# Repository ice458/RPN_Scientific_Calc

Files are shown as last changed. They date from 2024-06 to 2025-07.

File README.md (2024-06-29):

# RPN Scientific Calculator
RPN Scientific Calculator with PIC32CM2532LE00048.  
Reverse Polish notation with 4-element stack.  
This calculator uses a proprietary decimal floating point library to perform calculations.  
This project was created using MPLAB X IDE v6.20, XC32 v4.35, and MCC v5.50.  
For more information, please visit [this site.](https://ice458.wordpress.com/rpn%e9%96%a2%e6%95%b0%e9%9b%bb%e5%8d%93/)

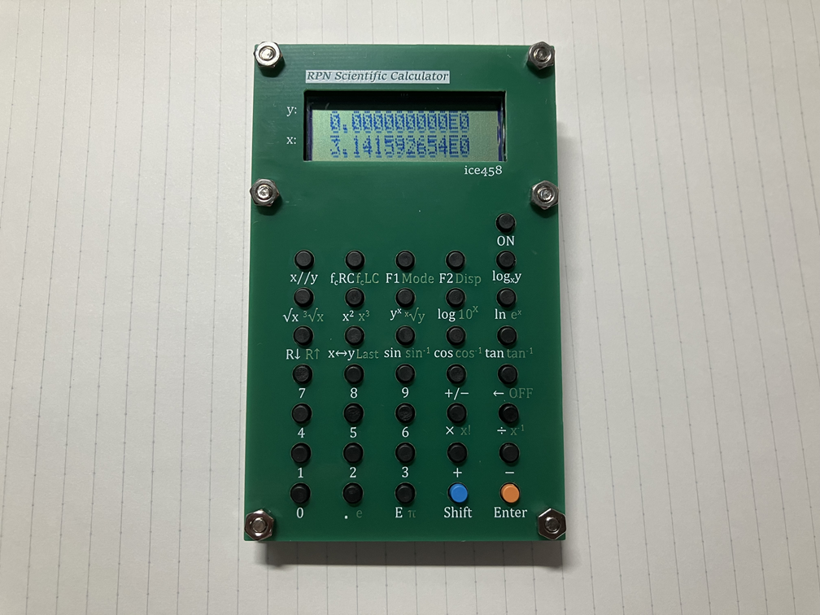
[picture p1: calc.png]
  

## License

This project is licensed under the MIT License. See the [LICENSE](LICENSE) file for details.

## Notice Regarding Third-Party Code

Please note that the copyright of the files contained in the directories [src/packs](src/packs) and [src/config](src/config) does not belong to ice458. These files include code that is subject to third-party licenses. Please refer to the comments at the top of these files for specific licensing information.

The directories [src/packs](src/packs) and [src/config](src/config) may contain files licensed under the Apache License 2.0 and Microchip's proprietary license. You must comply with these licenses when using or distributing these files.

### Apache License 2.0

Portions of this project are licensed under the Apache License 2.0. You may obtain a copy of the License at http://www.apache.org/licenses/LICENSE-2.0.

### Microchip Proprietary License

Certain files are subject to Microchip's proprietary license. These files are provided by Microchip "as is" without any warranties, and you may use Microchip software and any derivatives exclusively with Microchip products. Refer to the comments within the files for more details on the terms and conditions.

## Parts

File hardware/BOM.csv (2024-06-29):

Reference | Value | Datasheet | Footprint | Qty
BT1 | AAA | ~ | Battery:BatteryHolder_Keystone_2466_1xAAA | 1
C1,C7,C11,C14 | GRM188R71E105KA12 | ~ | Capacitor_SMD:C_0603_1608Metric | 4
C2,C3,C8,C9,C10,C12,C13 | GRM188F11H104ZA01 | ~ | Capacitor_SMD:C_0603_1608Metric | 7
C4 | GRM31CR61A107MEA8 | ~ | Capacitor_SMD:C_1206_3216Metric | 1
C5,C6 | GRM188R6YA106MA73 | ~ | Capacitor_SMD:C_0603_1608Metric | 2
D1,D2,D3,D4,D5,D6,D7,D8 | 1N4148W | ~ | Diode_SMD:D_SOD-123 | 8
J1 | PICKIT4/5 | ~ | Connector_PinHeader_2.54mm:PinHeader_1x08_P2.54mm_Vertical | 1
L1 | DFE252010P-4R7M=P2 | ~ | Inductor_SMD:L_1008_2520Metric | 1
L2 | DFE252012F-100M=P2 | ~ | Inductor_SMD:L_1008_2520Metric | 1
Q1 | 2N7002H | ~ | Package_TO_SOT_SMD:SOT-23 | 1
Q2 | AO3415A | ~ | Package_TO_SOT_SMD:SOT-23 | 1
R1,R2,R3,R6,R7,R8,R9,R10,R11 | ERJ-3EKF1002V | ~ | Resistor_SMD:R_0603_1608Metric | 9
R4 | ERJ-3EKF1003V | ~ | Resistor_SMD:R_0603_1608Metric | 1
R5 | ERJ-3EKF1001V | ~ | Resistor_SMD:R_0603_1608Metric | 1
SW1,SW2,SW3,SW4,SW5,SW6,SW7,SW8,SW9,SW10,SW11,SW12,SW13,SW14,SW15,SW16,SW17,SW18,SW19,SW20,SW21,SW22,SW23,SW24,SW25,SW26,SW27,SW28,SW29,SW30,SW31,SW32,SW33,SW34,SW35,SW36 | DTS-63-N-V-BLK | ~ | Button_Switch_THT:SW_PUSH_6mm | 36
U1 | AQM1602Y-RN-GBW | ~ | My_Display:AQM1602Y-RN-GBW | 1
U2 | XC9140A331MR-G | ~ | Package_TO_SOT_SMD:SOT-23-5 | 1
U3 | PIC32CM2532LE00048-I/Y8X | ~ | Package_QFP:TQFP-48_7x7mm_P0.5mm | 1

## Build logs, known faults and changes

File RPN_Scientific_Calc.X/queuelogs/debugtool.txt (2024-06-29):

268 1719630796392 GEN4_CONNECT_DIAGNOSTICS:MPLABCommTool is NOT null
268 1719630796393 GEN4_CONNECT_DIAGNOSTICS:AttachedToolPID = 9012, AttachedToolVID = 4d8
268 1719630796393 GEN4_CONNECT_DIAGNOSTICS:transport type = USB
268 1719630796394 GEN4_CONNECT_DIAGNOSTICS:AttachedToolPID = 9012, AttachedToolVID = 4d8
268 1719630796505 com.microchip.mplab.mdbcore.RealICETool.RIDbgToolCom
268 1719630796505 GEN4_CONNECT_DIAGNOSTICS:Before MPLABCommTool.Connect()
268 1719630796506 GEN4_CONNECT_DIAGNOSTICS:After MPLABCommTool.Connect()
268 1719630796551 GEN4_CONNECT_DIAGNOSTICS:Adding new plug and play observer com.microchip.mplab.mdbcore.RI4Tool.RI4ToolBase$RI4PlugNPlayObserver@505a1f4a
268 1719630796551 GEN4_CONNECT_DIAGNOSTICS:Begin PlugNPlayObservers list dump:
268 1719630796552 GEN4_CONNECT_DIAGNOSTICS:com.microchip.mplab.mdbcore.RI4Tool.RI4ToolBase$RI4PlugNPlayObserver@505a1f4a
268 1719630796552 GEN4_CONNECT_DIAGNOSTICS:End PlugNPlayObservers list dump:
268 1719630796557 GEN4_CONNECT_DIAGNOSTICS:Registering for alternate PNP notifications. CommPnPCriteria.cPIDList = [2177, 2179, 217a, 2141, 9017, 901b, 9036, 9035], CommPnPCriteria.cSerialNumber = bur191452614

268 1719630797563 GEN4_TO_CONTROLLER_LOG:GEN4_INIT_INT_LOG_PIC32CM2532LE00048 Pre:init
268 1719630797563 GEN4_TO_CONTROLLER_LOG:GEN4_INIT_INT_LOG_PIC32CM2532LE00048 Payload
268 1719630797564 GEN4_TO_CONTROLLER_LOG:GEN4_INIT_INT_LOG_PIC32CM2532LE00048 DeviceInfo: Values:
268 1719630797564 GEN4_TO_CONTROLLER_LOG:GEN4_INIT_INT_LOG_PIC32CM2532LE00048 DeviceInfo: pcAddress = 7fffffffffffffff, Vpp = 3.30, useRowEraseIfVoltageIsLow = false, voltageBelowWhichUseRowErase = 0.00, deviceName = PIC32CM2532LE00048, programmerType = NVMCTRL_U2207
268 1719630797564 GEN4_TO_CONTROLLER_LOG:GEN4_INIT_INT_LOG_PIC32CM2532LE00048 DeviceInfo: MemInfo values:
268 1719630797564 GEN4_TO_CONTROLLER_LOG:GEN4_INIT_INT_LOG_PIC32CM2532LE00048 DeviceInfo: mask = ffffffff, exists = true, startAddr = 00000000, endAddr = 20007fff, rowSize = 0100, rowEraseSize = 0100, addrInc = 0004, widthProgram = 0004
268 1719630797564 GEN4_TO_CONTROLLER_LOG:GEN4_INIT_INT_LOG_PIC32CM2532LE00048 DeviceInfo: mask = ffffffff, exists = true, startAddr = 00804000, endAddr = 0080c04f, rowSize = 0100, rowEraseSize = 0000, addrInc = 0004, widthProgram = 0004
268 1719630797564 GEN4_TO_CONTROLLER_LOG:GEN4_INIT_INT_LOG_PIC32CM2532LE00048 DeviceInfo: mask = 0000, exists = false, startAddr = 00000000, endAddr = 00000000, rowSize = 0000, rowEraseSize = 0000, addrInc = 0000, widthProgram = 0000
268 1719630797564 GEN4_TO_CONTROLLER_LOG:GEN4_INIT_INT_LOG_PIC32CM2532LE00048 DeviceInfo: mask = 0000, exists = false, startAddr = 00000000, endAddr = 00000000, rowSize = 0000, rowEraseSize = 0000, addrInc = 0000, widthProgram = 0000
268 1719630797564 GEN4_TO_CONTROLLER_LOG:GEN4_INIT_INT_LOG_PIC32CM2532LE00048 DeviceInfo: mask = ffffffff, exists = true, startAddr = 00804008, endAddr = 008040ff, rowSize = 0100, rowEraseSize = 0000, addrInc = 0004, widthProgram = 0004
268 1719630797565 GEN4_TO_CONTROLLER_LOG:GEN4_INIT_INT_LOG_PIC32CM2532LE00048 DeviceInfo: mask = 0000, exists = false, startAddr = 00000000, endAddr = 00000000, rowSize = 0000, rowEraseSize = 0100, addrInc = 0000, widthProgram = 0000
268 1719630797565 GEN4_TO_CONTROLLER_LOG:GEN4_INIT_INT_LOG_PIC32CM2532LE00048 DeviceInfo: mask = 0000, exists = false, startAddr = 00000000, endAddr = 00000000, rowSize = 0000, rowEraseSize = 0000, addrInc = 0004, widthProgram = 0004
268 1719630797565 GEN4_TO_CONTROLLER_LOG:GEN4_INIT_INT_LOG_PIC32CM2532LE00048 DeviceInfo: mask = ffffffff, exists = true, startAddr = 40000000, endAddr = e000efff, rowSize = 0000, rowEraseSize = 0000, addrInc = 0004, widthProgram = 0004
268 1719630797565 GEN4_TO_CONTROLLER_LOG:GEN4_INIT_INT_LOG_PIC32CM2532LE00048 DeviceInfo: mask = 0000, exists = true, startAddr = 00400000, endAddr = 00401ffe, rowSize = 0000, rowEraseSize = 0000, addrInc = 0004, widthProgram = 0004
268 1719630797565 GEN4_TO_CONTROLLER_LOG:GEN4_INIT_INT_LOG_PIC32CM2532LE00048 DeviceInfo: mask = 0000, exists = false, startAddr = 00000000, endAddr = 00000000, rowSize = 0000, rowEraseSize = 0000, addrInc = 0000, widthProgram = 0000
268 1719630797565 GEN4_TO_CONTROLLER_LOG:GEN4_INIT_INT_LOG_PIC32CM2532LE00048 DeviceInfo: mask = 0000, exists = false, startAddr = 00000000, endAddr = 00000000, rowSize = 0000, rowEraseSize = 0000, addrInc = 0004, widthProgram = 0004
268 1719630797565 GEN4_TO_CONTROLLER_LOG:GEN4_INIT_INT_LOG_PIC32CM2532LE00048 DeviceInfo: mask = 0000, exists = false, startAddr = 00000000, endAddr = 00000000, rowSize = 0000, rowEraseSize = 0000, addrInc = 0004, widthProgram = 0004
268 1719630797565 GEN4_TO_CONTROLLER_LOG:GEN4_INIT_INT_LOG_PIC32CM2532LE00048 DeviceInfo: mask = 0000, exists = false, startAddr = 00000000, endAddr = 00000000, rowSize = 0000, rowEraseSize = 0000, addrInc = 0000, widthProgram = 0000
268 1719630797565 GEN4_TO_CONTROLLER_LOG:GEN4_INIT_INT_LOG_PIC32CM2532LE00048 DeviceInfo: mask = 0000, exists = false, startAddr = 00000000, endAddr = 00000000, rowSize = 0000, rowEraseSize = 0000, addrInc = 0000, widthProgram = 0000
268 1719630797565 GEN4_TO_CONTROLLER_LOG:GEN4_INIT_INT_LOG_PIC32CM2532LE00048 DeviceInfo: mask = 0000, exists = false, startAddr = 00000000, endAddr = 00000000, rowSize = 0000, rowEraseSize = 0000, addrInc = 0000, widthProgram = 0000
268 1719630797565 GEN4_TO_CONTROLLER_LOG:GEN4_INIT_INT_LOG_PIC32CM2532LE00048 DeviceInfo: mask = 0000, exists = false, startAddr = 00000000, endAddr = 00000000, rowSize = 0000, rowEraseSize = 0000, addrInc = 0000, widthProgram = 0000
268 1719630797565 GEN4_TO_CONTROLLER_LOG:GEN4_INIT_INT_LOG_PIC32CM2532LE00048 DeviceInfo: mask = 7fffffff, exists = true, startAddr = 41002018, endAddr = 4100201b, rowSize = 0001, rowEraseSize = 0000, addrInc = 0001, widthProgram = 0001
268 1719630797565 GEN4_TO_CONTROLLER_LOG:GEN4_INIT_INT_LOG_PIC32CM2532LE00048 DeviceInfo: mask = 0000, exists = false, startAddr = 00000000, endAddr = 00000000, rowSize = 0000, rowEraseSize = 0000, addrInc = 0000, widthProgram = 0000
268 1719630797565 GEN4_TO_CONTROLLER_LOG:GEN4_INIT_INT_LOG_PIC32CM2532LE00048 DeviceInfo: mask = 0000, exists = false, startAddr = 00000000, endAddr = 00000000, rowSize = 0000, rowEraseSize = 0000, addrInc = 0000, widthProgram = 0000
268 1719630797565 GEN4_TO_CONTROLLER_LOG:GEN4_INIT_INT_LOG_PIC32CM2532LE00048 DeviceInfo: mask = 0000, exists = false, startAddr = 00000000, endAddr = 00000000, rowSize = 0000, rowEraseSize = 0000, addrInc = 0000, widthProgram = 0000
268 1719630797565 GEN4_TO_CONTROLLER_LOG:GEN4_INIT_INT_LOG_PIC32CM2532LE00048 DeviceInfo: mask = 0000, exists = false, startAddr = 00000000, endAddr = 00000000, rowSize = 0000, rowEraseSize = 0000, addrInc = 0000, widthProgram = 0000
268 1719630797565 GEN4_TO_CONTROLLER_LOG:GEN4_INIT_INT_LOG_PIC32CM2532LE00048 DeviceInfo: mask = 0000, exists = false, startAddr = 00000000, endAddr = 00000000, rowSize = 0000, rowEraseSize = 0000, addrInc = 0000, widthProgram = 0000
268 1719630797565 GEN4_TO_CONTROLLER_LOG:GEN4_INIT_INT_LOG_PIC32CM2532LE00048 DeviceInfo: mask = 0000, exists = false, startAddr = 00000000, endAddr = 00000000, rowSize = 0000, rowEraseSize = 0000, addrInc = 0000, widthProgram = 0000
268 1719630797565 GEN4_TO_CONTROLLER_LOG:GEN4_INIT_INT_LOG_PIC32CM2532LE00048 DeviceInfo: CfgRequiredBitsMask Values:
268 1719630797566 GEN4_TO_CONTROLLER_LOG:GEN4_INIT_INT_LOG_PIC32CM2532LE00048 Address = 00804000, Mask = fe00ffbf
268 1719630797566 GEN4_TO_CONTROLLER_LOG:GEN4_INIT_INT_LOG_PIC32CM2532LE00048 Address = 00804004, Mask = 000003ff
268 1719630797566 GEN4_TO_CONTROLLER_LOG:GEN4_INIT_INT_LOG_PIC32CM2532LE00048 Address = 0080c004, Mask = 0007ff00
268 1719630797566 GEN4_TO_CONTROLLER_LOG:GEN4_INIT_INT_LOG_PIC32CM2532LE00048 Address = 0080c040, Mask = ffffffff
268 1719630797566 GEN4_TO_CONTROLLER_LOG:GEN4_INIT_INT_LOG_PIC32CM2532LE00048 Address = 0080c044, Mask = ffffffff
268 1719630797566 GEN4_TO_CONTROLLER_LOG:GEN4_INIT_INT_LOG_PIC32CM2532LE00048 Address = 0080c048, Mask = ffffffff
268 1719630797566 GEN4_TO_CONTROLLER_LOG:GEN4_INIT_INT_LOG_PIC32CM2532LE00048 Address = 0080c04c, Mask = ffffffff
268 1719630797566 GEN4_TO_CONTROLLER_LOG:GEN4_INIT_INT_LOG_PIC32CM2532LE00048 BasicInfo: Values:
268 1719630797566 GEN4_TO_CONTROLLER_LOG:GEN4_INIT_INT_LOG_PIC32CM2532LE00048 BasicInfo: InputStream = com.microchip.mplab.libs.toolpacksupport.EquatableFileInputStream@1fa17626, ToolFlavor = PICKit4
268 1719630797566 GEN4_TO_CONTROLLER_LOG:GEN4_INIT_INT_LOG_PIC32CM2532LE00048 Payload End
268 1719630802489 GEN4_TO_CONTROLLER_LOG:GEN4_INIT_INT_LOG_PIC32CM2532LE00048 Post:init
268 1719630802489 GEN4_TO_CONTROLLER_LOG:GEN4_INIT_INT_LOG_PIC32CM2532LE00048 Return Value
268 1719630802489 GEN4_TO_CONTROLLER_LOG:GEN4_INIT_INT_LOG_PIC32CM2532LE00048 none
268 1719630802489 GEN4_TO_CONTROLLER_LOG:GEN4_INIT_INT_LOG_PIC32CM2532LE00048 Return End

268 1719630802489 GEN4_TO_CONTROLLER_LOG:GEN4_INIT_INT_LOG_PIC32CM2532LE00048 Pre:GetInterfaceProvider
268 1719630802489 GEN4_TO_CONTROLLER_LOG:GEN4_INIT_INT_LOG_PIC32CM2532LE00048 Payload
268 1719630802489 GEN4_TO_CONTROLLER_LOG:GEN4_INIT_INT_LOG_PIC32CM2532LE00048 RI4DebugInterface
268 1719630802489 GEN4_TO_CONTROLLER_LOG:GEN4_INIT_INT_LOG_PIC32CM2532LE00048 Payload End
268 1719630802489 GEN4_TO_CONTROLLER_LOG:GEN4_INIT_INT_LOG_PIC32CM2532LE00048 Post:GetInterfaceProvider
268 1719630802489 GEN4_TO_CONTROLLER_LOG:GEN4_INIT_INT_LOG_PIC32CM2532LE00048 Return Value
268 1719630802489 GEN4_TO_CONTROLLER_LOG:GEN4_INIT_INT_LOG_PIC32CM2532LE00048 com.microchip.mplab.libs.scriptbasedcontroller.implementations.DebugImplWithAtmelIceHelp@77af45e2
268 1719630802489 GEN4_TO_CONTROLLER_LOG:GEN4_INIT_INT_LOG_PIC32CM2532LE00048 Return End

268 1719630802522 GEN4_TO_CONTROLLER_LOG:GEN4_INIT_INT_LOG_PIC32CM2532LE00048 Pre:GetInterfaceProvider
268 1719630802522 GEN4_TO_CONTROLLER_LOG:GEN4_INIT_INT_LOG_PIC32CM2532LE00048 Payload
268 1719630802522 GEN4_TO_CONTROLLER_LOG:GEN4_INIT_INT_LOG_PIC32CM2532LE00048 RI4ProgramInterface
268 1719630802522 GEN4_TO_CONTROLLER_LOG:GEN4_INIT_INT_LOG_PIC32CM2532LE00048 Payload End
268 1719630802522 GEN4_TO_CONTROLLER_LOG:GEN4_INIT_INT_LOG_PIC32CM2532LE00048 Post:GetInterfaceProvider
268 1719630802522 GEN4_TO_CONTROLLER_LOG:GEN4_INIT_INT_LOG_PIC32CM2532LE00048 Return Value
268 1719630802522 GEN4_TO_CONTROLLER_LOG:GEN4_INIT_INT_LOG_PIC32CM2532LE00048 com.microchip.mplab.libs.scriptbasedcontroller.implementations.ProgramImpl@31d8782b
268 1719630802522 GEN4_TO_CONTROLLER_LOG:GEN4_INIT_INT_LOG_PIC32CM2532LE00048 Return End

268 1719630802555 GEN4_TO_CONTROLLER_LOG:GEN4_INIT_INT_LOG_PIC32CM2532LE00048 Pre:GetInterfaceProvider
268 1719630802555 GEN4_TO_CONTROLLER_LOG:GEN4_INIT_INT_LOG_PIC32CM2532LE00048 Payload
268 1719630802555 GEN4_TO_CONTROLLER_LOG:GEN4_INIT_INT_LOG_PIC32CM2532LE00048 RI4ConnectInterface
268 1719630802555 GEN4_TO_CONTROLLER_LOG:GEN4_INIT_INT_LOG_PIC32CM2532LE00048 Payload End
268 1719630802555 GEN4_TO_CONTROLLER_LOG:GEN4_INIT_INT_LOG_PIC32CM2532LE00048 Post:GetInterfaceProvider
268 1719630802555 GEN4_TO_CONTROLLER_LOG:GEN4_INIT_INT_LOG_PIC32CM2532LE00048 Return Value
268 1719630802555 GEN4_TO_CONTROLLER_LOG:GEN4_INIT_INT_LOG_PIC32CM2532LE00048 com.microchip.mplab.libs.scriptbasedcontroller.implementations.ICD4TrapCallDeviceIDCommunicationsImpl@2694c1c1
268 1719630802555 GEN4_TO_CONTROLLER_LOG:GEN4_INIT_INT_LOG_PIC32CM2532LE00048 Return End
268 1719630802568 GEN4_CONNECT_DIAGNOSTICS:acceptablePIDs = [9012, 9017, 901b, 9036, 9035]
268 1719630802568 GEN4_CONNECT_DIAGNOSTICS:otherPIDs = [2177, 2179, 217a, 2141]
268 1719630802568 GEN4_CONNECT_DIAGNOSTICS:Setting selected tool type to pk4
268 1719630802568 GEN4_CONNECT_DIAGNOSTICS:otherPIDs = [2177, 2179, 217a, 2141]
268 1719630802568 GEN4_CONNECT_DIAGNOSTICS:acceptablePIDs = [9012, 9017, 901b, 9036, 9035]

268 1719630802573 GEN4_TO_CONTROLLER_LOG:GEN4_CONNECT_INT_LOG_PIC32CM2532LE00048 Pre:selectCore
268 1719630802573 GEN4_TO_CONTROLLER_LOG:GEN4_CONNECT_INT_LOG_PIC32CM2532LE00048 Payload
268 1719630802573 GEN4_TO_CONTROLLER_LOG:GEN4_CONNECT_INT_LOG_PIC32CM2532LE00048 PIC32CM2532LE00048
268 1719630802573 GEN4_TO_CONTROLLER_LOG:GEN4_CONNECT_INT_LOG_PIC32CM2532LE00048 Payload End
268 1719630802573 GEN4_TO_CONTROLLER_LOG:GEN4_CONNECT_INT_LOG_PIC32CM2532LE00048 Post:selectCore
268 1719630802573 GEN4_TO_CONTROLLER_LOG:GEN4_CONNECT_INT_LOG_PIC32CM2532LE00048 Return Value
268 1719630802573 GEN4_TO_CONTROLLER_LOG:GEN4_CONNECT_INT_LOG_PIC32CM2532LE00048 none
268 1719630802573 GEN4_TO_CONTROLLER_LOG:GEN4_CONNECT_INT_LOG_PIC32CM2532LE00048 Return End

268 1719630802573 GEN4_TO_CONTROLLER_LOG:GEN4_INIT_INT_LOG_PIC32CM2532LE00048 Pre:GetInterfaceProvider
268 1719630802573 GEN4_TO_CONTROLLER_LOG:GEN4_INIT_INT_LOG_PIC32CM2532LE00048 Payload
268 1719630802573 GEN4_TO_CONTROLLER_LOG:GEN4_INIT_INT_LOG_PIC32CM2532LE00048 RI4ControllerDiagnosticsInterface
268 1719630802573 GEN4_TO_CONTROLLER_LOG:GEN4_INIT_INT_LOG_PIC32CM2532LE00048 Payload End
268 1719630802574 GEN4_TO_CONTROLLER_LOG:GEN4_INIT_INT_LOG_PIC32CM2532LE00048 Post:GetInterfaceProvider
268 1719630802574 GEN4_TO_CONTROLLER_LOG:GEN4_INIT_INT_LOG_PIC32CM2532LE00048 Return Value
268 1719630802574 GEN4_TO_CONTROLLER_LOG:GEN4_INIT_INT_LOG_PIC32CM2532LE00048 com.microchip.mplab.libs.atmelice.implementations.UnimplementedDiagnostics@3344ed22
268 1719630802574 GEN4_TO_CONTROLLER_LOG:GEN4_INIT_INT_LOG_PIC32CM2532LE00048 Return End

268 1719630802574 GEN4_TO_CONTROLLER_LOG:GEN4_INIT_INT_LOG_PIC32CM2532LE00048 Pre:GetInterfaceProvider
268 1719630802574 GEN4_TO_CONTROLLER_LOG:GEN4_INIT_INT_LOG_PIC32CM2532LE00048 Payload
268 1719630802574 GEN4_TO_CONTROLLER_LOG:GEN4_INIT_INT_LOG_PIC32CM2532LE00048 ProgrammerToGo
268 1719630802574 GEN4_TO_CONTROLLER_LOG:GEN4_INIT_INT_LOG_PIC32CM2532LE00048 Payload End
268 1719630802575 GEN4_TO_CONTROLLER_LOG:GEN4_INIT_INT_LOG_PIC32CM2532LE00048 Post:GetInterfaceProvider
268 1719630802575 GEN4_TO_CONTROLLER_LOG:GEN4_INIT_INT_LOG_PIC32CM2532LE00048 Return Value
268 1719630802575 GEN4_TO_CONTROLLER_LOG:GEN4_INIT_INT_LOG_PIC32CM2532LE00048 null
268 1719630802575 GEN4_TO_CONTROLLER_LOG:GEN4_INIT_INT_LOG_PIC32CM2532LE00048 Return End

268 1719630802575 GEN4_TO_CONTROLLER_LOG:GEN4_INIT_INT_LOG_PIC32CM2532LE00048 Pre:GetInterfaceProvider
268 1719630802575 GEN4_TO_CONTROLLER_LOG:GEN4_INIT_INT_LOG_PIC32CM2532LE00048 Payload
268 1719630802575 GEN4_TO_CONTROLLER_LOG:GEN4_INIT_INT_LOG_PIC32CM2532LE00048 Status
268 1719630802575 GEN4_TO_CONTROLLER_LOG:GEN4_INIT_INT_LOG_PIC32CM2532LE00048 Payload End
268 1719630802575 GEN4_TO_CONTROLLER_LOG:GEN4_INIT_INT_LOG_PIC32CM2532LE00048 Post:GetInterfaceProvider
268 1719630802575 GEN4_TO_CONTROLLER_LOG:GEN4_INIT_INT_LOG_PIC32CM2532LE00048 Return Value
268 1719630802575 GEN4_TO_CONTROLLER_LOG:GEN4_INIT_INT_LOG_PIC32CM2532LE00048 null
268 1719630802575 GEN4_TO_CONTROLLER_LOG:GEN4_INIT_INT_LOG_PIC32CM2532LE00048 Return End
268 1719630802615 GEN4_CONNECT_DIAGNOSTICS:ENTERING: com.microchip.mplab.mdbcore.RI4Tool.ConnectionHandler.CheckForFWUpdates()
268 1719630802615 GEN4_CONNECT_DIAGNOSTICS:Created FirmwareUpdateHandler com.microchip.mplab.mdbcore.pk4hybrid.pk4hybridFirmwareUpdateHandler@4bcc16e6
268 1719630802616 GEN4_CONNECT_DIAGNOSTICS:ENTERING: com.microchip.mplab.mdbcore.pk4hybrid.pk4hybridFirmwareUpdateHandler.UpdateFirmware(FirmwareInfo, UpdateMessage)
268 1719630802624 GEN4_CONNECT_DIAGNOSTICS:areWeInBoot returned false
268 1719630802624 GEN4_CONNECT_DIAGNOSTICS:inBoot = false
268 1719630802624 GEN4_CONNECT_DIAGNOSTICS:uMode = checkingVersions
268 1719630802624 GEN4_CONNECT_DIAGNOSTICS:selectedTool = pk4
268 1719630802624 GEN4_CONNECT_DIAGNOSTICS:current toolType = pk4
268 1719630802624 GEN4_CONNECT_DIAGNOSTICS:current tool mode = pk4
268 1719630802624 GEN4_CONNECT_DIAGNOSTICS:ENTERING: com.microchip.mplab.mdbcore.pk4hybrid.pk4hybridFirmwareUpdateHandler.GetUpdateInfo()
268 1719630802627 GEN4_CONNECT_DIAGNOSTICS:Parsing file  for firmware updates
268 1719630802627 GEN4_CONNECT_DIAGNOSTICS:ENTERING: com.microchip.mplab.mdbcore.pk4hybrid.pk4hybridFirmwareUpdateHandler.ParseSelectedVersionsFromJamFile()
268 1719630802628 GEN4_CONNECT_DIAGNOSTICS:Jame file line = boot.hex,010000
268 1719630802628 GEN4_CONNECT_DIAGNOSTICS:Jame file line = scripts.xml,000671
268 1719630802628 GEN4_CONNECT_DIAGNOSTICS:Jame file line = app1 020135, 0040C000
268 1719630802628 GEN4_CONNECT_DIAGNOSTICS:Jame file line = app2 1.15.20, 00500000
268 1719630802628 GEN4_CONNECT_DIAGNOSTICS:Jame file line = app3 000000, FFFFFFFF
268 1719630802628 GEN4_CONNECT_DIAGNOSTICS:Jame file line = app4 000000, FFFFFFFF
268 1719630802628 GEN4_CONNECT_DIAGNOSTICS:Jame file line = app5 000000, FFFFFFFF
268 1719630802628 GEN4_CONNECT_DIAGNOSTICS:Jame file line = app6 000000, FFFFFFFF
268 1719630802628 GEN4_CONNECT_DIAGNOSTICS:Jame file line = app7 000000, FFFFFFFF
268 1719630802628 GEN4_CONNECT_DIAGNOSTICS:Jame file line = app8 000000, FFFFFFFF
268 1719630802628 GEN4_CONNECT_DIAGNOSTICS:EXITING: com.microchip.mplab.mdbcore.pk4hybrid.pk4hybridFirmwareUpdateHandler.ri4ParseSelectedVersionsFromJamFile()
268 1719630802628 GEN4_CONNECT_DIAGNOSTICS:EXITING: com.microchip.mplab.mdbcore.pk4hybrid.pk4hybridFirmwareUpdateHandler.GetUpdateInfo()
268 1719630802628 GEN4_CONNECT_DIAGNOSTICS:current toolType = pk4

268 1719630802628 GEN4_TO_CONTROLLER_LOG:GEN4_CONNECT_INT_LOG_PIC32CM2532LE00048 Pre:EstablishCommunincations
268 1719630802628 GEN4_TO_CONTROLLER_LOG:GEN4_CONNECT_INT_LOG_PIC32CM2532LE00048 Payload
268 1719630802628 GEN4_TO_CONTROLLER_LOG:GEN4_CONNECT_INT_LOG_PIC32CM2532LE00048 com.microchip.mplab.mdbcore.PK4Tool.PK4Com@1e13c42f
268 1719630802628 GEN4_TO_CONTROLLER_LOG:GEN4_CONNECT_INT_LOG_PIC32CM2532LE00048 Payload End
268 1719630802658 ExecuteFunCall.call debug_write_supports_flash
268 1719630802659 ExecuteFunCall.call begin_communication_session
268 1719630802673 GEN4_TO_CONTROLLER_LOG:GEN4_CONNECT_INT_LOG_PIC32CM2532LE00048 Post:EstablishCommunincations
268 1719630802673 GEN4_TO_CONTROLLER_LOG:GEN4_CONNECT_INT_LOG_PIC32CM2532LE00048 Return Value
268 1719630802677 GEN4_TO_CONTROLLER_LOG:GEN4_CONNECT_INT_LOG_PIC32CM2532LE00048 true
268 1719630802677 GEN4_TO_CONTROLLER_LOG:GEN4_CONNECT_INT_LOG_PIC32CM2532LE00048 Return End

268 1719630802677 GEN4_TO_CONTROLLER_LOG:GEN4_CONNECT_INT_LOG_PIC32CM2532LE00048 Pre:GetFirmwareInfo
268 1719630802677 GEN4_TO_CONTROLLER_LOG:GEN4_CONNECT_INT_LOG_PIC32CM2532LE00048 Payload
268 1719630802677 GEN4_TO_CONTROLLER_LOG:GEN4_CONNECT_INT_LOG_PIC32CM2532LE00048 null
268 1719630802677 GEN4_TO_CONTROLLER_LOG:GEN4_CONNECT_INT_LOG_PIC32CM2532LE00048 Payload End
268 1719630802685 XXXX 1719630802685, Thread 268: com.Send returned false 
268 1719630802687 XXXX 1719630802687, Thread 268: execCommand: exception after writeSideChanel null

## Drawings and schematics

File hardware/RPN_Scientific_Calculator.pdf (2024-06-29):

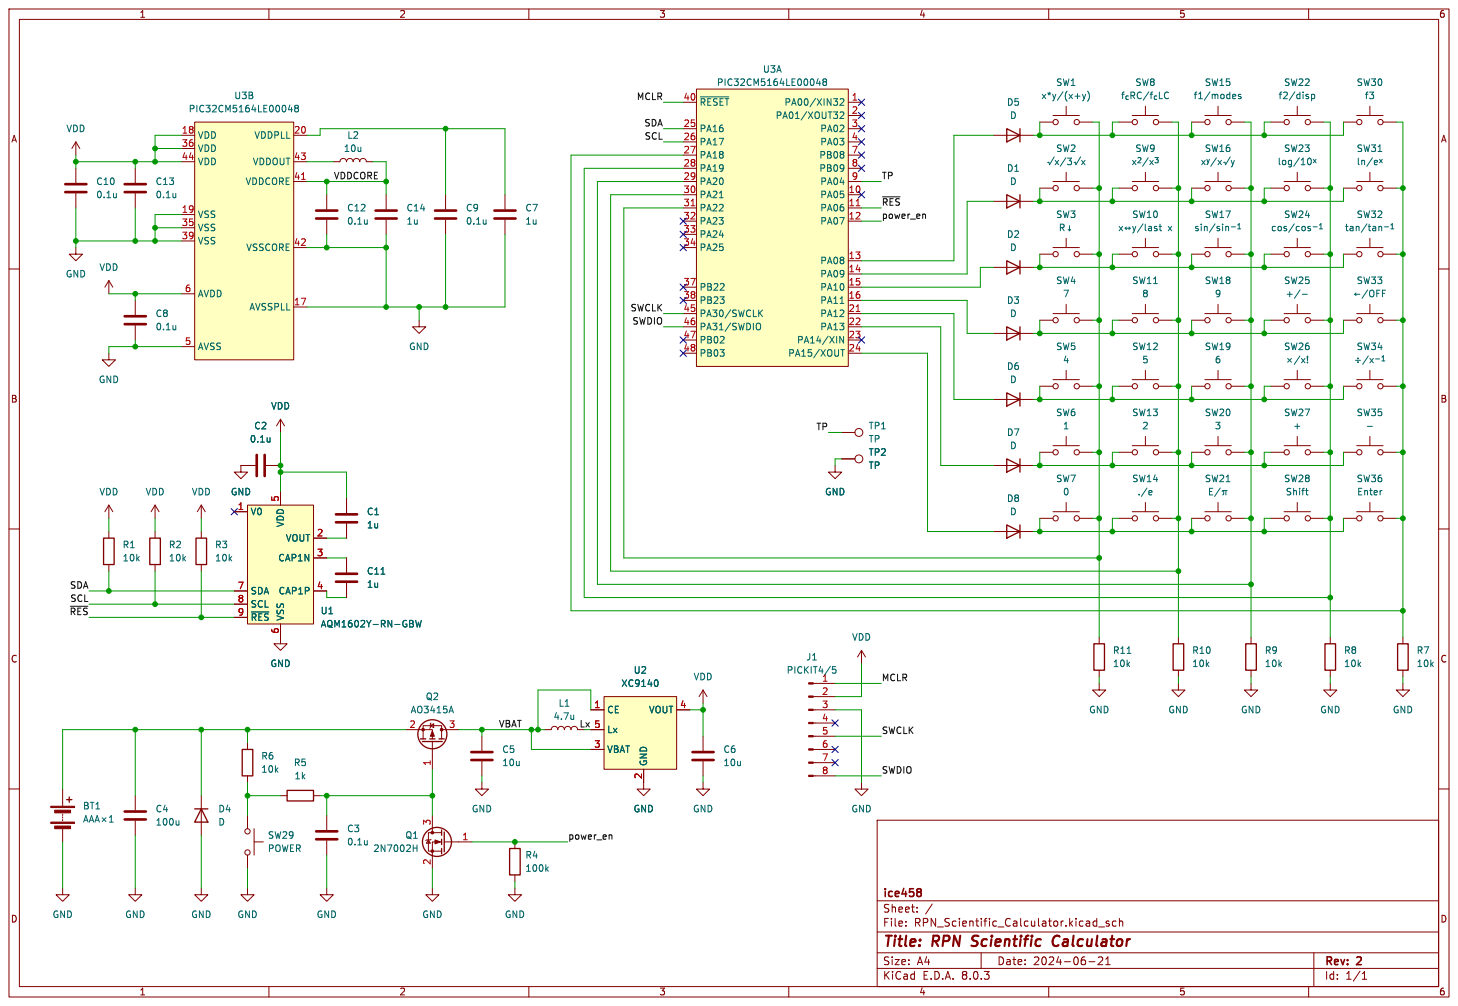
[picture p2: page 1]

6 SDA 7 SCL 8 ~{RES} 9 U1AQM1602Y-RN-GBW

6 SDA 7 SCL 8 ~{RES} 9 GND

ice458
Id: 1/1 Title: RPN Scientific Calculator File: RPN_Scientific_Calculator.kicad_sch Sheet: /

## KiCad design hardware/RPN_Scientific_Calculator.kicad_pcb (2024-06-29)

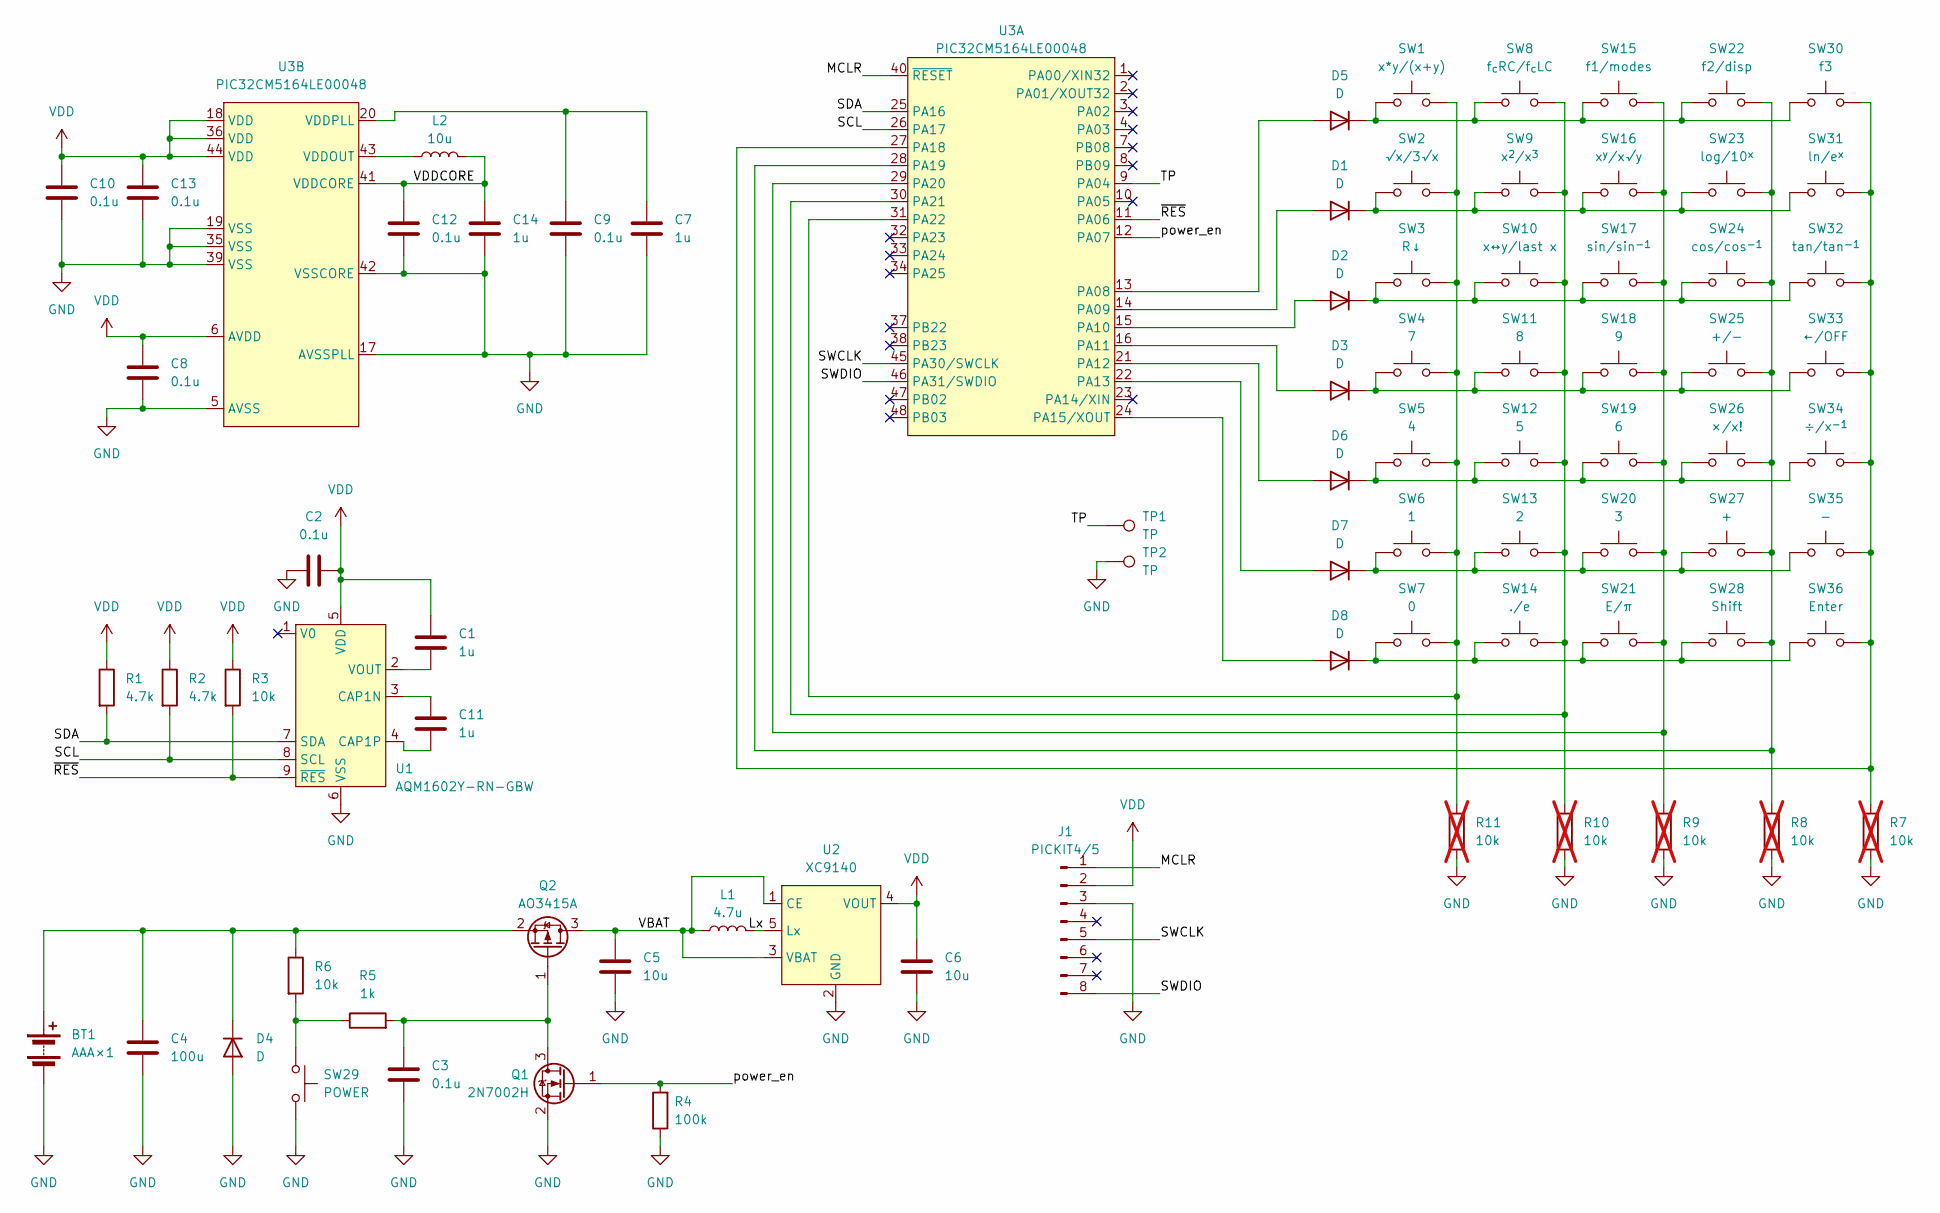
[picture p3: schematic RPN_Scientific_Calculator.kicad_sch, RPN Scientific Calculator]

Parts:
BT1: AAA×1; BatteryHolder_Keystone_2466_1xAAA
C1, C7, C11, C14: 1u; C_0603_1608Metric
C2, C3, C8, C9, C10, C12, C13: 0.1u; C_0603_1608Metric
C4: 100u; C_1206_3216Metric
C5, C6: 10u; C_0603_1608Metric
D1, D2, D3, D4, D5, D6, D7, D8: D; D_SOD-123
J1: PICKIT4/5; PinHeader_1x08_P2.54mm_Vertical
L1: 4.7u; L_1008_2520Metric
L2: 10u; L_1008_2520Metric
Q1: 2N7002H; SOT-23
Q2: AO3415A; SOT-23
R1, R2: 4.7k; R_0603_1608Metric
R3, R6: 10k; R_0603_1608Metric
R4: 100k; R_0603_1608Metric
R5: 1k; R_0603_1608Metric
R7, R8, R9, R10, R11: 10k; R_0603_1608Metric; not fitted
SW1: x*y/(x+y); SW_PUSH_6mm
SW2: √x/3√x; SW_PUSH_6mm
SW3: R↓; SW_PUSH_6mm
SW4: 7; SW_PUSH_6mm
SW5: 4; SW_PUSH_6mm
SW6: 1; SW_PUSH_6mm
SW7: 0; SW_PUSH_6mm
SW8: f_{c}RC/f_{c}LC; SW_PUSH_6mm
SW9: x^{2}/x^{3}; SW_PUSH_6mm
SW10: x↔y/last x; SW_PUSH_6mm
SW11: 8; SW_PUSH_6mm
SW12: 5; SW_PUSH_6mm
SW13: 2; SW_PUSH_6mm
SW14: ./e; SW_PUSH_6mm
SW15: f1/modes; SW_PUSH_6mm
SW16: x^{y}/x√y; SW_PUSH_6mm
SW17: sin/sin^{-1}; SW_PUSH_6mm
SW18: 9; SW_PUSH_6mm
SW19: 6; SW_PUSH_6mm
SW20: 3; SW_PUSH_6mm
SW21: E/π; SW_PUSH_6mm
SW22: f2/disp; SW_PUSH_6mm
SW23: log/10^{x}; SW_PUSH_6mm
SW24: cos/cos^{-1}; SW_PUSH_6mm
SW25: +/-; SW_PUSH_6mm
SW26: ×/x!; SW_PUSH_6mm
SW27: +; SW_PUSH_6mm
SW28: Shift; SW_PUSH_6mm
SW29: POWER; SW_PUSH_6mm
SW30: f3; SW_PUSH_6mm
SW31: ln/e^{x}; SW_PUSH_6mm
SW32: tan/tan^{-1}; SW_PUSH_6mm
SW33: ←/OFF; SW_PUSH_6mm
SW34: ÷/x^{-1}; SW_PUSH_6mm
SW35: -; SW_PUSH_6mm
SW36: Enter; SW_PUSH_6mm
TP1, TP2: TP; TestPoint_Pad_D1.0mm
U1: AQM1602Y-RN-GBW
U2: XC9140; SOT-23-5
U3: PIC32CM5164LE00048; TQFP-48_7x7mm_P0.5mm

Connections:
/Lx: L1.2, U2.5 (Lx)
/MCLR: J1.1, U3.40 (~RESET)
/SCL: R2.2, U1.8 (SCL), U3.26 (PA17)
/SDA: R1.2, U1.7 (SDA), U3.25 (PA16)
/SWCLK: J1.5, U3.45 (PA30/SWCLK)
/SWDIO: J1.8, U3.46 (PA31/SWDIO)
/TP: TP1.1, U3.9 (PA04)
/VBAT: C5.2, L1.1, Q2.3 (D), U2.1 (CE), U2.3 (VBAT)
/VDDCORE: C12.2, C14.2, L2.2, U3.41 (VDDCORE)
/power_en: Q1.1 (G), R4.2, U3.12 (PA07)
/~RES: R3.2, U1.9 (~RES), U3.11 (PA06)
GND: BT1.2 (-), C2.1, C3.1, C4.1, C5.1, C6.1, C7.1, C8.1, C9.1, C10.1, C12.1, C13.1, C14.1, D4.2 (A), J1.3, Q1.2 (S), R4.1, R7.2, R8.2, R9.2, R10.2, R11.2, SW29.2, TP2.1, U1.6 (VSS), U2.2 (GND), U3.5 (AVSS), U3.17 (AVSSPLL), U3.19 (VSS), U3.35 (VSS), U3.39 (VSS), U3.42 (VSSCORE)
unnamed: BT1.1 (+), C4.2, D4.1 (K), Q2.2 (S), R6.1
unnamed: D1.2 (A), U3.14 (PA09)
unnamed: D1.1 (K), SW2.1, SW9.1, SW16.1, SW23.1, SW31.1
unnamed: D2.2 (A), U3.15 (PA10)
unnamed: D2.1 (K), SW3.1, SW10.1, SW17.1, SW24.1, SW32.1
unnamed: D3.2 (A), U3.16 (PA11)
unnamed: D3.1 (K), SW4.1, SW11.1, SW18.1, SW25.1, SW33.1
unnamed: D5.2 (A), U3.13 (PA08)
unnamed: D5.1 (K), SW1.1, SW8.1, SW15.1, SW22.1, SW30.1
unnamed: D6.2 (A), U3.21 (PA12)
unnamed: D6.1 (K), SW5.1, SW12.1, SW19.1, SW26.1, SW34.1
unnamed: D7.2 (A), U3.22 (PA13)
unnamed: D7.1 (K), SW6.1, SW13.1, SW20.1, SW27.1, SW35.1
unnamed: D8.2 (A), U3.24 (PA15/XOUT)
unnamed: D8.1 (K), SW7.1, SW14.1, SW21.1, SW28.1, SW36.1
unnamed: C3.2, Q1.3 (D), Q2.1 (G), R5.2
unnamed: R5.1, R6.2, SW29.1
unnamed: C11.2, U1.3 (CAP1N)
unnamed: C11.1, U1.4 (CAP1P)
unnamed: C1.1, U1.2 (VOUT)
unnamed: R7.1, SW30.2, SW31.2, SW32.2, SW33.2, SW34.2, SW35.2, SW36.2, U3.27 (PA18)
unnamed: R8.1, SW22.2, SW23.2, SW24.2, SW25.2, SW26.2, SW27.2, SW28.2, U3.28 (PA19)
unnamed: R9.1, SW15.2, SW16.2, SW17.2, SW18.2, SW19.2, SW20.2, SW21.2, U3.29 (PA20)
unnamed: R10.1, SW8.2, SW9.2, SW10.2, SW11.2, SW12.2, SW13.2, SW14.2, U3.30 (PA21)
unnamed: R11.1, SW1.2, SW2.2, SW3.2, SW4.2, SW5.2, SW6.2, SW7.2, U3.31 (PA22)
unnamed: L2.1, U3.43 (VDDOUT)
unnamed: C7.2, C9.2, U3.20 (VDDPLL)
VDD: C1.2, C2.2, C6.2, C8.2, C10.2, C13.2, J1.2, R1.1, R2.1, R3.1, U1.5 (VDD), U2.4 (VOUT), U3.6 (AVDD), U3.18 (VDD), U3.36 (VDD), U3.44 (VDD)

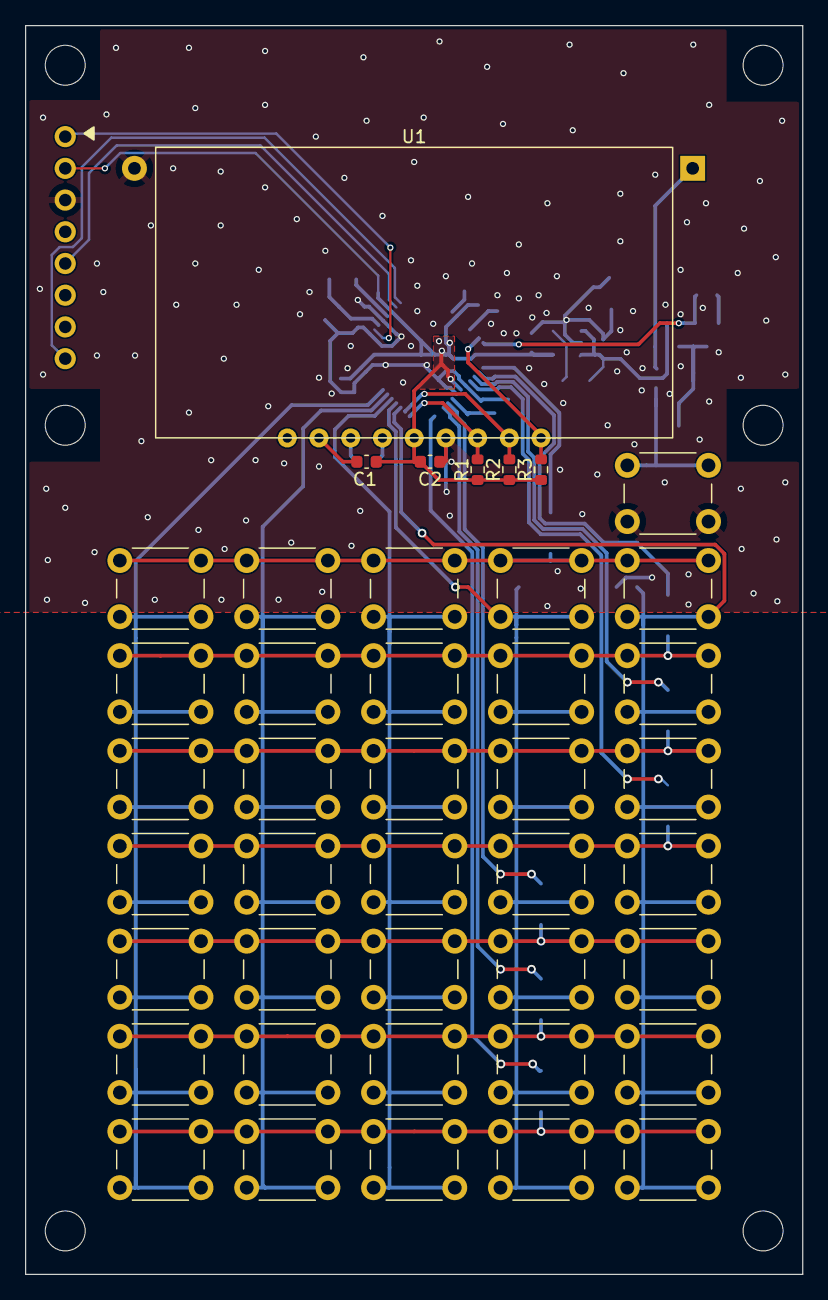
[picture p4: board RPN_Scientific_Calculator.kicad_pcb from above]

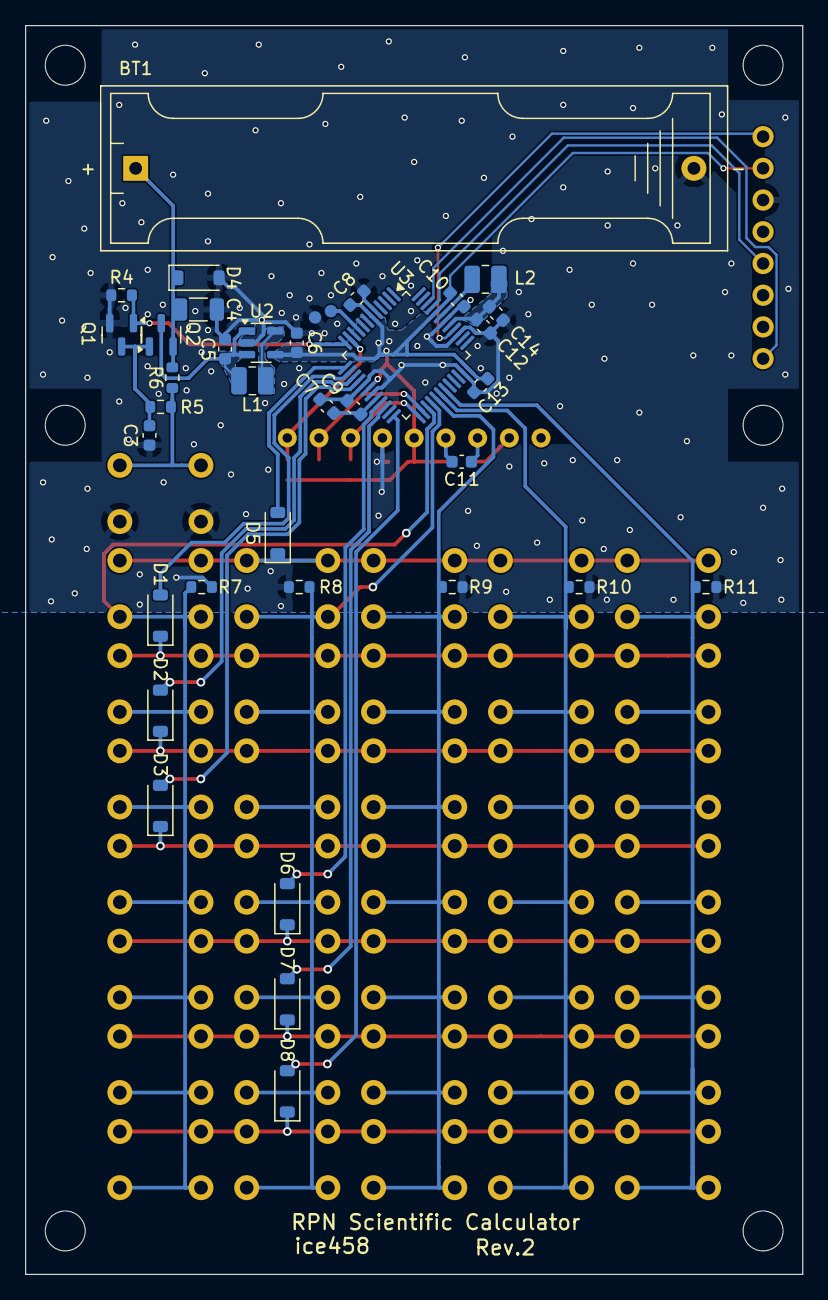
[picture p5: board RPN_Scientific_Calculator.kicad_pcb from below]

Board: 2 copper layers, 62.2 x 100.0 mm, 86 parts (37 on the bottom side), 40 nets.

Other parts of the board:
REF1, REF2, REF3, REF4, REF5, REF6: MountingHole_3.2mm_M3

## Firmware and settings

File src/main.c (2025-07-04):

#include <stddef.h>
#include <stdint.h>
#include <stdbool.h>
#include <stdlib.h>
#include <stdio.h>
#include "definitions.h"

#include "AQM1602Y.h"
#include "switch.h"
#include "decimal_float.h"
#include "delay.h"

// *****************************************************************************
// *****************************************************************************
// 定数定義
// *****************************************************************************
// *****************************************************************************
#define MAX_INPUTVAL_LENGTH 18
#define CONFIG_BUFFER_SIZE 8
#define DISPLAY_WIDTH 16
#define STACK_SIZE 4
#define POWER_SAVE_TIMEOUT_MS 600000 // 10分

// *****************************************************************************
// *****************************************************************************
// スタック操作関連
// *****************************************************************************
// *****************************************************************************
df_t stack[STACK_SIZE];

void stack_init()
{
    int_to_df(0, &stack[0]);
    int_to_df(0, &stack[1]);
    int_to_df(0, &stack[2]);
    int_to_df(0, &stack[3]);
}

void stack_push()
{
    stack[3] = stack[2];
    stack[2] = stack[1];
    stack[1] = stack[0];
}

void stack_pop()
{
    stack[0] = stack[1];
    stack[1] = stack[2];
    stack[2] = stack[3];
}

void stack_swap()
{
    df_swap(&stack[0], &stack[1]);
}

void stack_roll_up()
{
    df_t tmp = stack[3];
    stack[3] = stack[2];
    stack[2] = stack[1];
    stack[1] = stack[0];
    stack[0] = tmp;
}

void stack_roll_down()
{
    df_t tmp = stack[0];
    stack[0] = stack[1];
    stack[1] = stack[2];
    stack[2] = stack[3];
    stack[3] = tmp;
}

// *****************************************************************************
// *****************************************************************************
// ヘルパー関数
// *****************************************************************************
// *****************************************************************************

// 入力値をクリアする
void clear_input_state(char *inputval, uint8_t *inputval_len, uint8_t *pos_E,
                       uint8_t *pos_dot, bool *pri_m, bool *pri_e)
{
    for (uint8_t i = 0; i < MAX_INPUTVAL_LENGTH; i++)
    {
        inputval[i] = '\0';
    }
    *inputval_len = 0;
    *pos_E = 0;
    *pos_dot = 0;
    *pri_m = false;
    *pri_e = false;
}

// 数字入力共通関数
void handle_digit_input(char digit, char *inputval, uint8_t *inputval_len,
                        bool *push_flag, df_t *stack, uint8_t *pos_E,
                        uint8_t *pos_dot, bool *pri_m, bool *pri_e)
{
    if (*push_flag == true)
    {
        *push_flag = false;
        df_t tmp = stack[0];
        stack_push();
        clear_input_state(inputval, inputval_len, pos_E, pos_dot, pri_m, pri_e);
        stack[0] = tmp;
    }
    if (*inputval_len < MAX_INPUTVAL_LENGTH)
    {
        inputval[*inputval_len] = digit;
        (*inputval_len)++;
    }
    string_to_df(inputval, &stack[0]);
}

// 演算後共通処理
void after_operation(char *inputval, uint8_t *inputval_len, uint8_t *pos_E,
                     uint8_t *pos_dot, bool *pri_m, bool *pri_e,
                     bool *shift, bool *push_flag)
{
    clear_input_state(inputval, inputval_len, pos_E, pos_dot, pri_m, pri_e);
    *shift = false;
    *push_flag = true;
}

// クロック周波数制御
void set_low_frequency_clock()
{
    while(SERCOM1_I2C_IsBusy());
    delay_ms(1);
    // GCLK0をOSCULP32Kに変更
    GCLK_REGS->GCLK_GENCTRL[0] = GCLK_GENCTRL_DIV(1U) | GCLK_GENCTRL_SRC(3U) | GCLK_GENCTRL_GENEN_Msk;
    while ((GCLK_REGS->GCLK_SYNCBUSY & GCLK_SYNCBUSY_GENCTRL0_Msk) == GCLK_SYNCBUSY_GENCTRL0_Msk)
        ;
    // DFLLをOFF
    OSCCTRL_REGS->OSCCTRL_DFLLCTRL = OSCCTRL_DFLLCTRL_ENABLE(false);
}

void set_high_frequency_clock()
{
    // DFLLをON
    OSCCTRL_REGS->OSCCTRL_DFLLCTRL = OSCCTRL_DFLLCTRL_ENABLE_Msk;
    while ((OSCCTRL_REGS->OSCCTRL_STATUS & OSCCTRL_STATUS_DFLLRDY_Msk) != OSCCTRL_STATUS_DFLLRDY_Msk)
        ;
    // GCLK0をDFLL48Mに変更
    GCLK_REGS->GCLK_GENCTRL[0] = GCLK_GENCTRL_DIV(1U) | GCLK_GENCTRL_SRC(7U) | GCLK_GENCTRL_GENEN_Msk;
    while ((GCLK_REGS->GCLK_SYNCBUSY & GCLK_SYNCBUSY_GENCTRL0_Msk) == GCLK_SYNCBUSY_GENCTRL0_Msk)
        ;
}

// *****************************************************************************
// *****************************************************************************
// 設定読み書き
// *****************************************************************************
// *****************************************************************************
uint32_t poweron_setting[CONFIG_BUFFER_SIZE];

// flashから設定を読み込む
void read_config()
{
    uint32_t buf[CONFIG_BUFFER_SIZE];
    NVMCTRL_Read(buf, CONFIG_BUFFER_SIZE, NVMCTRL_USERROW_START_ADDRESS);
    if (buf[0] & 1)
    {
        set_df_angle_mode(DF_ANGLE_MODE_RAD);
        poweron_setting[0] = 1;
    }
    else
    {
        set_df_angle_mode(DF_ANGLE_MODE_DEG);
        poweron_setting[0] = 0;
    }
    if (buf[1] & 1)
    {
        set_df_string_mode(DF_STRING_MODE_SCIENTIFIC);
        poweron_setting[1] = 1;
    }
    else
    {
        set_df_string_mode(DF_STRING_MODE_ENGINEERING);
        poweron_setting[1] = 0;
    }
}

// flashに書き込む
void write_config()
{
    uint32_t buf[CONFIG_BUFFER_SIZE] = {0};
    switch (get_df_angle_mode())
    {
    case DF_ANGLE_MODE_DEG:
        buf[0] = 0;
        break;
    case DF_ANGLE_MODE_RAD:
        buf[0] = 1;
        break;
    default:
        break;
    }
    switch (get_df_string_mode())
    {
    case DF_STRING_MODE_ENGINEERING:
        buf[1] = 0;
        break;
    case DF_STRING_MODE_SCIENTIFIC:
        buf[1] = 1;
        break;
    default:
        break;
    }

    if (poweron_setting[0] != buf[0] || poweron_setting[1] != buf[1])
    {
        NVMCTRL_USER_ROW_RowErase(NVMCTRL_USERROW_START_ADDRESS);
        while (NVMCTRL_IsBusy())
            ;
        NVMCTRL_USER_ROW_PageWrite(buf, NVMCTRL_USERROW_START_ADDRESS);
        while (NVMCTRL_IsBusy())
            ;
    }
}

// *****************************************************************************
// *****************************************************************************
// 各種設定画面の表示
// *****************************************************************************
// *****************************************************************************

void config(bool mode_flag, bool disp_flag)
{
    AQM1602Y_Clear();
    // 表示文字列のバッファ
    char str[17];
    // 演算用一時変数
    df_t tmp;
    // キーナンバー
    uint8_t key = 254;      // ダミー初期値
    uint8_t last_key = 255; // ダミー初期値
    // キーが押されたかどうかのフラグ
    bool is_pushed = false;

    while (1)
    {
        set_low_frequency_clock();

        // キー読み取り開始
        TC2_TimerStart();
        // キー読み取りループ
        while (1)
        {
            WDT_Clear();
            if (last_key == 255)
            {
                last_key = 0;
                break;
            }
            key = key_read();
            if (key != last_key)
            {
                last_key = key;
                break;
            }
        }
        // オートパワーセーブ用タイマリセット
        TC0_Timer16bitCounterSet(0);
        // キー読み取りストップ
        TC2_TimerStop();

        set_high_frequency_clock();

        // キー押下
        is_pushed = true;

        // キー解釈
        switch (key)
        {
        case KENTER:
            return;
            break;
        case K1:
            if (mode_flag == true)
            {
                set_df_angle_mode(DF_ANGLE_MODE_DEG);
            }
            else if (disp_flag == true)
            {
                set_df_string_mode(DF_STRING_MODE_ENGINEERING);
            }
            break;
        case K2:
            if (mode_flag == true)
            {
                set_df_angle_mode(DF_ANGLE_MODE_RAD);
            }
            else if (disp_flag == true)
            {
                set_df_string_mode(DF_STRING_MODE_SCIENTIFIC);
            }
            break;
        case 0:
            is_pushed = false;
            break;
        default:
            break;
        }

        // 表示処理
        if (is_pushed == true)
        {
            if (mode_flag == true)
            {
                AQM1602Y_Corsor_YX(1, 0);
                AQM1602Y_Print("  1.DEG  2.RAD  ", 16);
                switch (get_df_angle_mode())
                {
                case DF_ANGLE_MODE_DEG:
                    AQM1602Y_Corsor_YX(1, 1);
                    AQM1602Y_Print("*", 1);
                    break;
                case DF_ANGLE_MODE_RAD:
                    AQM1602Y_Corsor_YX(1, 8);
                    AQM1602Y_Print("*", 1);
                    break;
                default:
                    break;
                }
            }
            else if (disp_flag == true)
            {
                AQM1602Y_Corsor_YX(1, 0);
                AQM1602Y_Print("  1.ENG  2.SCI  ", 16);
                switch (get_df_string_mode())
                {
                case DF_STRING_MODE_ENGINEERING:
                    AQM1602Y_Corsor_YX(1, 1);
                    AQM1602Y_Print("*", 1);
                    break;
                case DF_STRING_MODE_SCIENTIFIC:
                    AQM1602Y_Corsor_YX(1, 8);
                    AQM1602Y_Print("*", 1);
                    break;
                default:
                    break;
                }

                // Xレジスタの表示
                AQM1602Y_Corsor_YX(0, 0);
                AQM1602Y_Print("                ", 16);
                df_round(&stack[0], &tmp);
                df_to_string(&tmp, str);
                if (stack[0].sign == 0)
                {
                    AQM1602Y_Corsor_YX(0, 1);
                }
                else
                {
                    AQM1602Y_Corsor_YX(0, 0);
                }
                AQM1602Y_Print(str, 16);
            }
            delay_ms(10);
        }
    }
}

// *****************************************************************************
// *****************************************************************************
// 科学定数
// *****************************************************************************
// *****************************************************************************

// 科学定数の定義
typedef struct
{
    const char *name;
    df_t (*get_value)(void);
    const char *symbol;
} scientific_constant_t;

// 科学定数を取得する関数群
df_t get_speed_of_light(void)
{
    df_t result;
    // 光の速度 2.99792458E8 m/s
    string_to_df("2.99792458E8", &result);
    return result;
}

df_t get_planck_constant(void)
{
    df_t result;
    // プランク定数 6.62607015E-34 J⋅s
    string_to_df("6.62607015E-34", &result);
    return result;
}

df_t get_elementary_charge(void)
{
    df_t result;
    // 電気素量 1.602176634E-19 C
    string_to_df("1.602176634-19", &result);
    return result;
}

df_t get_avogadro_number(void)
{
    df_t result;
    // アボガドロ数 6.02214076E23 /mol
    string_to_df("6.02214076E23", &result);
    return result;
}

df_t get_boltzmann_constant(void)
{
    df_t result;
    // ボルツマン定数 1.380649E-23 J/K
    string_to_df("1.380649E-23", &result);
    return result;
}

df_t get_gas_constant(void)
{
    df_t result;
    // 気体定数 8.314462618 J/(mol⋅K)
    string_to_df("8.314462618", &result);
    return result;
}

df_t get_electron_mass(void)
{
    df_t result;
    // 電子質量 9.1093837015E-31 kg
    string_to_df("9.1093837015E-31", &result);
    return result;
}

df_t get_proton_mass(void)
{
    df_t result;
    // 陽子質量 1.67262192369E-27 kg
    string_to_df("1.67262192369E-27", &result);
    return result;
}

df_t get_neutron_mass(void)
{
    df_t result;
    // 中性子質量 1.67492749804E-27 kg
    string_to_df("1.67492749804E-27", &result);
    return result;
}

df_t get_atomic_mass_unit(void)
{
    df_t result;
    // 原子質量定数 1.66053906660E-27 kg
    string_to_df("1.66053906660E-27", &result);
    return result;
}

df_t get_gravitational_constant(void)
{
    df_t result;
    // 万有引力定数 6.67430E-11 m³/(kg·s²)
    string_to_df("6.67430E-11", &result);
    return result;
}

df_t get_standard_gravity(void)
{
    df_t result;
    // 標準重力加速度 9.80665 m/s²
    string_to_df("9.80665", &result);
    return result;
}

df_t get_stefan_boltzmann_constant(void)
{
    df_t result;
    // ステファン-ボルツマン定数 5.670374419E-8 W/(m²·K⁴)
    string_to_df("5.670374419E-8", &result);
    return result;
}

df_t get_rydberg_constant(void)
{
    df_t result;
    // リュードベリ定数 1.0973731568160E7 m⁻¹
    string_to_df("1.0973731568160E7", &result);
    return result;
}

df_t get_vacuum_permeability(void)
{
    df_t result;
    // 真空透磁率 μ₀ 1.25663706212E-6 H/m
    string_to_df("1.25663706212E-6", &result);
    return result;
}

df_t get_vacuum_permittivity(void)
{
    df_t result;
    // 真空誘電率 ε₀ 8.8541878128E-12 F/m
    string_to_df("8.8541878128E-12", &result);
    return result;
}

df_t get_impedance_of_free_space(void)
{
    df_t result;
    // 自由空間インピーダンス √(μ₀/ε₀) 376.730313667 Ω
    string_to_df("376.730313667", &result);
    return result;
}

df_t get_fine_structure_constant(void)
{
    df_t result;
    // 微細構造定数 α 7.2973525693E-3
    string_to_df("7.2973525693E-3", &result);
    return result;
}
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
int main(void)
{
    SYS_Initialize(NULL);

    // 電源ON状態をラッチ
    POWER_EN_Set();

    // オートパワーセーブ用タイマ設定
    // 割り込み周期 600,000msec (10min)
    TC0_TimerCallbackRegister(pdown, (uintptr_t)NULL);
    TC0_TimerStart();

    // WDT
    WDT_TimeoutPeriodSet(0x9); // 4秒
    WDT_Enable();

    // LCDの初期化
    AQM1602Y_Initialize();

    // キー読み取り機能の初期化
    init_sw();

    // 起動メッセージ表示
    AQM1602Y_Corsor_YX(1, 0);
    AQM1602Y_Print("     Hello!", 16);
    read_config();
    delay_ms(300);

    // スタックの初期化
    stack_init();
    // 表示文字列のバッファ
    char str[17];
    // 入力文字列のバッファ
    char inputval[MAX_INPUTVAL_LENGTH] = {0};
    // 入力された文字列の長さ
    uint8_t inputval_len = 0;
    // 指数表記のEの位置
    uint8_t pos_E = 0;
    // 小数点の位置
    uint8_t pos_dot = 0;
    // 仮数の符号(falseで正)
    bool pri_m = false;
    // 指数の符号(falseで正)
    bool pri_e = false;
    // 演算後に数値入力でpushするためのフラグ
    bool push_flag = false;

    // キーナンバー
    uint8_t key = 254;      // ダミー初期値
    uint8_t last_key = 255; // ダミー初期値

    // シフトキーのフラグ
    bool shift = false;
    // キーが押されたかどうかのフラグ
    bool is_pushed = false;
    // 演算用一時変数
    df_t tmp;
    // 直前のXレジスタの値
    df_t last_x;
    int_to_df(0, &last_x);
    // モード設定表示フラグ
    bool mode_flag = false;
    // 表示設定表示フラグ
    bool disp_flag = false;
    while (1)
    {
        set_low_frequency_clock();

        // キー読み取り開始
        TC2_TimerStart();

        // キー読み取りループ
        while (1)
        {
            WDT_Clear();
            if (last_key == 255)
            {
                last_key = 0;
                break;
            }
            key = key_read();
            if (key != last_key)
            {
                last_key = key;
                break;
            }
        }
        // オートパワーセーブ用タイマリセット
        TC0_Timer16bitCounterSet(0);
        // キー読み取りストップ
        TC2_TimerStop();

        set_high_frequency_clock();

        // キー押下
        is_pushed = true;

        // キー解釈
        switch (key)
        {
        case KSHIFT:
            shift ^= true;
            break;
        case KDEL:
            if (shift == true)
            {
                AQM1602Y_Corsor_YX(0, 0);
                AQM1602Y_Print("                ", 16);
                AQM1602Y_Corsor_YX(1, 0);
                AQM1602Y_Print("    See you!    ", 16);
                write_config();
                delay_ms(500);
                POWER_EN_Clear();
            }
            else
            {
                push_flag = false;
                if (0 < inputval_len && inputval_len < MAX_INPUTVAL_LENGTH)
                {
                    inputval_len--;
                    inputval[inputval_len] = '\0';
                    if (pos_E == inputval_len)
                    {
                        pos_E = 0;
                    }
                    if (pos_dot == inputval_len)
                    {
                        pos_dot = 0;
                    }
                    if (inputval_len == 0)
                    {
                        pri_m = false;
                    }
                }
                else
                {
                    for (uint8_t i = 0; i < MAX_INPUTVAL_LENGTH; i++)
                    {
                        inputval[i] = '\0';
                    }
                }
            }
            string_to_df(inputval, &stack[0]);
            shift = false;
            break;
        case K0:
            handle_digit_input('0', inputval, &inputval_len, &push_flag, stack,
                               &pos_E, &pos_dot, &pri_m, &pri_e);
            shift = false;
            break;
        case K1:
            handle_digit_input('1', inputval, &inputval_len, &push_flag, stack,
                               &pos_E, &pos_dot, &pri_m, &pri_e);
            shift = false;
            break;
        case K2:
            handle_digit_input('2', inputval, &inputval_len, &push_flag, stack,
                               &pos_E, &pos_dot, &pri_m, &pri_e);
            shift = false;
            break;
        case K3:
            handle_digit_input('3', inputval, &inputval_len, &push_flag, stack,
                               &pos_E, &pos_dot, &pri_m, &pri_e);
            shift = false;
            break;
        case K4:
            handle_digit_input('4', inputval, &inputval_len, &push_flag, stack,
                               &pos_E, &pos_dot, &pri_m, &pri_e);
            shift = false;
            break;
        case K5:
            handle_digit_input('5', inputval, &inputval_len, &push_flag, stack,
                               &pos_E, &pos_dot, &pri_m, &pri_e);
            shift = false;
            break;
        case K6:
            handle_digit_input('6', inputval, &inputval_len, &push_flag, stack,
                               &pos_E, &pos_dot, &pri_m, &pri_e);
            shift = false;
            break;
        case K7:
            handle_digit_input('7', inputval, &inputval_len, &push_flag, stack,
                               &pos_E, &pos_dot, &pri_m, &pri_e);
            shift = false;
            break;
        case K8:
            handle_digit_input('8', inputval, &inputval_len, &push_flag, stack,
                               &pos_E, &pos_dot, &pri_m, &pri_e);
            shift = false;
            break;
        case K9:
            handle_digit_input('9', inputval, &inputval_len, &push_flag, stack,
                               &pos_E, &pos_dot, &pri_m, &pri_e);
            shift = false;
            break;
        case KDOT:
            if (push_flag == true)
            {
                push_flag = false;
                tmp = stack[0];
                stack_push();
                for (uint8_t i = 0; i < MAX_INPUTVAL_LENGTH; i++)
                {
                    inputval[i] = '\0';
                }
                stack[0] = tmp;
            }
            if (shift == true)
            {
                stack[0] = df_e();
                after_operation(inputval, &inputval_len, &pos_E, &pos_dot, &pri_m, &pri_e, &shift, &push_flag);
                break;
            }
            else
            {
                if (pos_dot == 0 && pos_E == 0 && inputval_len != 0)
                {
                    if (inputval_len < MAX_INPUTVAL_LENGTH)
                    {
                        inputval[inputval_len] = '.';
                        pos_dot = inputval_len;
                        inputval_len++;
                    }
                }
                else if (pos_dot == 0 && pos_E == 0 && inputval_len == 0)
                {
                    if (inputval_len < MAX_INPUTVAL_LENGTH)
                    {
                        inputval[inputval_len] = '0';
                        inputval_len++;
                        inputval[inputval_len] = '.';
                        pos_dot = inputval_len;
                        inputval_len++;
                    }
                }
            }
            string_to_df(inputval, &stack[0]);
            shift = false;
            break;
        case KE:
            if (push_flag == true)
            {
                push_flag = false;
                tmp = stack[0];
                stack_push();
                for (uint8_t i = 0; i < MAX_INPUTVAL_LENGTH; i++)
                {
                    inputval[i] = '\0';
                }
                stack[0] = tmp;
            }
            if (shift == true)
            {
                stack[0] = df_pi();
                after_operation(inputval, &inputval_len, &pos_E, &pos_dot, &pri_m, &pri_e, &shift, &push_flag);
                break;
            }
            else
            {
                if (pos_E == 0 && inputval_len != 0)
                {
                    if (inputval_len < MAX_INPUTVAL_LENGTH)
                    {
                        inputval[inputval_len] = 'E';
                        pos_E = inputval_len;
                        inputval_len++;
                    }
                }
            }
            string_to_df(inputval, &stack[0]);
            shift = false;
            break;
        case KPRI:
            if (push_flag == true)
            {
                push_flag = false;
                tmp = stack[0];
                stack_push();
                for (uint8_t i = 0; i < MAX_INPUTVAL_LENGTH; i++)
                {
                    inputval[i] = '\0';
                }
                stack[0] = tmp;
            }
            if (pos_E == 0)
            {
                if (pri_m == false) // 負にするとき
                {
                    pri_m = true;
                    inputval_len++;
                    pos_dot = (pos_dot == 0) ? 0 : pos_dot + 1;
                    for (int8_t i = MAX_INPUTVAL_LENGTH - 2; i >= 0; i--)
                    {
                        inputval[i + 1] = inputval[i];
                    }
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

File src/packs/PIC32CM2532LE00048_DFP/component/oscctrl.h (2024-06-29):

/*
 * Component description for OSCCTRL
 *
 * Copyright (c) 2023 Microchip Technology Inc. and its subsidiaries.
 *
 * Subject to your compliance with these terms, you may use Microchip software and any derivatives
 * exclusively with Microchip products. It is your responsibility to comply with third party license
 * terms applicable to your use of third party software (including open source software) that may
 * accompany Microchip software.
 *
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
 * IN NO EVENT WILL MICROCHIP BE LIABLE FOR ANY INDIRECT, SPECIAL, PUNITIVE, INCIDENTAL OR CONSEQUENTIAL
 * LOSS, DAMAGE, COST OR EXPENSE OF ANY KIND WHATSOEVER RELATED TO THE SOFTWARE, HOWEVER CAUSED, EVEN IF
 * MICROCHIP HAS BEEN ADVISED OF THE POSSIBILITY OR THE DAMAGES ARE FORESEEABLE. TO THE FULLEST EXTENT
 * ALLOWED BY LAW, MICROCHIP'S TOTAL LIABILITY ON ALL CLAIMS IN ANY WAY RELATED TO THIS SOFTWARE WILL NOT
 * EXCEED THE AMOUNT OF FEES, IF ANY, THAT YOU HAVE PAID DIRECTLY TO MICROCHIP FOR THIS SOFTWARE.
 *
 */

/* file generated from device description version 2022-09-09T06:08:26Z */
#ifndef _PIC32CMLE00_OSCCTRL_COMPONENT_H_
#define _PIC32CMLE00_OSCCTRL_COMPONENT_H_

/* ************************************************************************** */
/*   SOFTWARE API DEFINITION FOR OSCCTRL                                      */
/* ************************************************************************** */

/* -------- OSCCTRL_EVCTRL : (OSCCTRL Offset: 0x00) (R/W 8) Event Control -------- */
#define OSCCTRL_EVCTRL_RESETVALUE             _UINT8_(0x00)                                        /*  (OSCCTRL_EVCTRL) Event Control  Reset Value */

#define OSCCTRL_EVCTRL_CFDEO_Pos              _UINT8_(0)                                           /* (OSCCTRL_EVCTRL) Clock Failure Detector Event Output Enable Position */
#define OSCCTRL_EVCTRL_CFDEO_Msk              (_UINT8_(0x1) << OSCCTRL_EVCTRL_CFDEO_Pos)           /* (OSCCTRL_EVCTRL) Clock Failure Detector Event Output Enable Mask */
#define OSCCTRL_EVCTRL_CFDEO(value)           (OSCCTRL_EVCTRL_CFDEO_Msk & (_UINT8_(value) << OSCCTRL_EVCTRL_CFDEO_Pos)) /* Assigment of value for CFDEO in the OSCCTRL_EVCTRL register */
#define OSCCTRL_EVCTRL_TUNEEI_Pos             _UINT8_(1)                                           /* (OSCCTRL_EVCTRL) Tune Event Input Enable Position */
#define OSCCTRL_EVCTRL_TUNEEI_Msk             (_UINT8_(0x1) << OSCCTRL_EVCTRL_TUNEEI_Pos)          /* (OSCCTRL_EVCTRL) Tune Event Input Enable Mask */
#define OSCCTRL_EVCTRL_TUNEEI(value)          (OSCCTRL_EVCTRL_TUNEEI_Msk & (_UINT8_(value) << OSCCTRL_EVCTRL_TUNEEI_Pos)) /* Assigment of value for TUNEEI in the OSCCTRL_EVCTRL register */
#define OSCCTRL_EVCTRL_TUNEINV_Pos            _UINT8_(2)                                           /* (OSCCTRL_EVCTRL) Tune Event Input Invert Position */
#define OSCCTRL_EVCTRL_TUNEINV_Msk            (_UINT8_(0x1) << OSCCTRL_EVCTRL_TUNEINV_Pos)         /* (OSCCTRL_EVCTRL) Tune Event Input Invert Mask */
#define OSCCTRL_EVCTRL_TUNEINV(value)         (OSCCTRL_EVCTRL_TUNEINV_Msk & (_UINT8_(value) << OSCCTRL_EVCTRL_TUNEINV_Pos)) /* Assigment of value for TUNEINV in the OSCCTRL_EVCTRL register */
#define OSCCTRL_EVCTRL_Msk                    _UINT8_(0x07)                                        /* (OSCCTRL_EVCTRL) Register Mask  */


/* -------- OSCCTRL_INTENCLR : (OSCCTRL Offset: 0x04) (R/W 32) Interrupt Enable Clear -------- */
#define OSCCTRL_INTENCLR_RESETVALUE           _UINT32_(0x00)                                       /*  (OSCCTRL_INTENCLR) Interrupt Enable Clear  Reset Value */
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

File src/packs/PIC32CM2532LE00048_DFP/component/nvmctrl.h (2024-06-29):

/*
 * Component description for NVMCTRL
 *
 * Copyright (c) 2023 Microchip Technology Inc. and its subsidiaries.
 *
 * Subject to your compliance with these terms, you may use Microchip software and any derivatives
 * exclusively with Microchip products. It is your responsibility to comply with third party license
 * terms applicable to your use of third party software (including open source software) that may
 * accompany Microchip software.
 *
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
 * IN NO EVENT WILL MICROCHIP BE LIABLE FOR ANY INDIRECT, SPECIAL, PUNITIVE, INCIDENTAL OR CONSEQUENTIAL
 * LOSS, DAMAGE, COST OR EXPENSE OF ANY KIND WHATSOEVER RELATED TO THE SOFTWARE, HOWEVER CAUSED, EVEN IF
 * MICROCHIP HAS BEEN ADVISED OF THE POSSIBILITY OR THE DAMAGES ARE FORESEEABLE. TO THE FULLEST EXTENT
 * ALLOWED BY LAW, MICROCHIP'S TOTAL LIABILITY ON ALL CLAIMS IN ANY WAY RELATED TO THIS SOFTWARE WILL NOT
 * EXCEED THE AMOUNT OF FEES, IF ANY, THAT YOU HAVE PAID DIRECTLY TO MICROCHIP FOR THIS SOFTWARE.
 *
 */

/* file generated from device description version 2022-09-09T06:08:26Z */
#ifndef _PIC32CMLE00_NVMCTRL_COMPONENT_H_
#define _PIC32CMLE00_NVMCTRL_COMPONENT_H_

/* ************************************************************************** */
/*   SOFTWARE API DEFINITION FOR NVMCTRL                                      */
/* ************************************************************************** */

/* -------- NVMCTRL_CTRLA : (NVMCTRL Offset: 0x00) ( /W 16) Control A -------- */
#define NVMCTRL_CTRLA_RESETVALUE              _UINT16_(0x00)                                       /*  (NVMCTRL_CTRLA) Control A  Reset Value */

#define NVMCTRL_CTRLA_CMD_Pos                 _UINT16_(0)                                          /* (NVMCTRL_CTRLA) Command Position */
#define NVMCTRL_CTRLA_CMD_Msk                 (_UINT16_(0x7F) << NVMCTRL_CTRLA_CMD_Pos)            /* (NVMCTRL_CTRLA) Command Mask */
#define NVMCTRL_CTRLA_CMD(value)              (NVMCTRL_CTRLA_CMD_Msk & (_UINT16_(value) << NVMCTRL_CTRLA_CMD_Pos)) /* Assigment of value for CMD in the NVMCTRL_CTRLA register */
#define   NVMCTRL_CTRLA_CMD_ER_Val            _UINT16_(0x2)                                        /* (NVMCTRL_CTRLA) Erase Row - Erases the row addressed by the ADDR register.  */
#define   NVMCTRL_CTRLA_CMD_WP_Val            _UINT16_(0x4)                                        /* (NVMCTRL_CTRLA) Write Page - Writes the contents of the page buffer to the page addressed by the ADDR register.  */
#define   NVMCTRL_CTRLA_CMD_SPRM_Val          _UINT16_(0x42)                                       /* (NVMCTRL_CTRLA) Sets the power reduction mode.  */
#define   NVMCTRL_CTRLA_CMD_CPRM_Val          _UINT16_(0x43)                                       /* (NVMCTRL_CTRLA) Clears the power reduction mode.  */
#define   NVMCTRL_CTRLA_CMD_PBC_Val           _UINT16_(0x44)                                       /* (NVMCTRL_CTRLA) Page Buffer Clear - Clears the page buffer.  */
#define   NVMCTRL_CTRLA_CMD_INVALL_Val        _UINT16_(0x46)                                       /* (NVMCTRL_CTRLA) Invalidate all cache lines.  */
#define   NVMCTRL_CTRLA_CMD_SDAL0_Val         _UINT16_(0x4B)                                       /* (NVMCTRL_CTRLA) Set DAL=0  */
#define NVMCTRL_CTRLA_CMD_ER                  (NVMCTRL_CTRLA_CMD_ER_Val << NVMCTRL_CTRLA_CMD_Pos)  /* (NVMCTRL_CTRLA) Erase Row - Erases the row addressed by the ADDR register. Position  */
#define NVMCTRL_CTRLA_CMD_WP                  (NVMCTRL_CTRLA_CMD_WP_Val << NVMCTRL_CTRLA_CMD_Pos)  /* (NVMCTRL_CTRLA) Write Page - Writes the contents of the page buffer to the page addressed by the ADDR register. Position  */
#define NVMCTRL_CTRLA_CMD_SPRM                (NVMCTRL_CTRLA_CMD_SPRM_Val << NVMCTRL_CTRLA_CMD_Pos) /* (NVMCTRL_CTRLA) Sets the power reduction mode. Position  */
#define NVMCTRL_CTRLA_CMD_CPRM                (NVMCTRL_CTRLA_CMD_CPRM_Val << NVMCTRL_CTRLA_CMD_Pos) /* (NVMCTRL_CTRLA) Clears the power reduction mode. Position  */
#define NVMCTRL_CTRLA_CMD_PBC                 (NVMCTRL_CTRLA_CMD_PBC_Val << NVMCTRL_CTRLA_CMD_Pos) /* (NVMCTRL_CTRLA) Page Buffer Clear - Clears the page buffer. Position  */
#define NVMCTRL_CTRLA_CMD_INVALL              (NVMCTRL_CTRLA_CMD_INVALL_Val << NVMCTRL_CTRLA_CMD_Pos) /* (NVMCTRL_CTRLA) Invalidate all cache lines. Position  */
#define NVMCTRL_CTRLA_CMD_SDAL0               (NVMCTRL_CTRLA_CMD_SDAL0_Val << NVMCTRL_CTRLA_CMD_Pos) /* (NVMCTRL_CTRLA) Set DAL=0 Position  */
#define NVMCTRL_CTRLA_CMDEX_Pos               _UINT16_(8)                                          /* (NVMCTRL_CTRLA) Command Execution Position */
#define NVMCTRL_CTRLA_CMDEX_Msk               (_UINT16_(0xFF) << NVMCTRL_CTRLA_CMDEX_Pos)          /* (NVMCTRL_CTRLA) Command Execution Mask */
#define NVMCTRL_CTRLA_CMDEX(value)            (NVMCTRL_CTRLA_CMDEX_Msk & (_UINT16_(value) << NVMCTRL_CTRLA_CMDEX_Pos)) /* Assigment of value for CMDEX in the NVMCTRL_CTRLA register */
#define   NVMCTRL_CTRLA_CMDEX_KEY_Val         _UINT16_(0xA5)                                       /* (NVMCTRL_CTRLA) Execution Key  */
#define NVMCTRL_CTRLA_CMDEX_KEY               (NVMCTRL_CTRLA_CMDEX_KEY_Val << NVMCTRL_CTRLA_CMDEX_Pos) /* (NVMCTRL_CTRLA) Execution Key Position  */
#define NVMCTRL_CTRLA_Msk                     _UINT16_(0xFF7F)                                     /* (NVMCTRL_CTRLA) Register Mask  */


/* -------- NVMCTRL_CTRLB : (NVMCTRL Offset: 0x04) (R/W 32) Control B -------- */
#define NVMCTRL_CTRLB_RESETVALUE              _UINT32_(0x00)                                       /*  (NVMCTRL_CTRLB) Control B  Reset Value */
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

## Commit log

2024-06-29 回路図の修正
    [RPN_Scientific_Calculator.kicad_sch]
2024-06-29 Add BOM
    [BOM.csv]
2024-07-02 三角関数の精度向上
2024-07-02 足し算の結果が負のゼロになる問題を修正
2024-07-02 三角関数が±1の範囲に収まるように修正
2024-07-02 設定画面から戻ったときに数値の入力を続行できるよう変更
2024-07-02 df_roundのバグ修正
2024-07-02 LASTキーの挙動を修正
2024-07-02 n th root のエラー処理を追加
2024-07-02 対数のエラー処理を実装
2024-07-03 内部計算桁数を12から18に変更
2024-07-04 expを改善
2024-07-04 対数の改善
2024-08-20 sqrt(0)と、負数のcbrtが正しく計算されない問題を修正
2025-02-02 0-0やlnのバグ修正、WDTの追加
2025-02-02 設定変更ができないバグを修正
2025-04-20 計算精度の改善 (ただしデバッグは不十分なので注意)
2025-04-23 逆数を計算済みにしておく
2025-04-23 MCC Coreバージョンアップ
2025-07-02 リファクタリングとバグ修正
2025-07-02 物理定数の機能を追加
2025-07-02 リファクタリング
2025-07-04 安全性の向上
2026-10-17 デモGIFを追加 (#1)
2026-10-17 プロジェクトページのリンクを更新
